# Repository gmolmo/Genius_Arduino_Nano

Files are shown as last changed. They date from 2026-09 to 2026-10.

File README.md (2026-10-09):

<h1 align="center"> 🔵🟢 Genius / Simon - Arduino 🟡🔴 </h1>

<div align="center">

  

</div>

## Descrição do Projeto
O projeto consiste no desenvolvimento do clássico jogo de memória **Genius (ou Simon)** utilizando um **Arduino Nano**. O objetivo do jogo é memorizar e repetir a sequência aleatória de luzes e sons apresentada pelos LEDs e buzzer. É possível selecionar a quantidade de rodadas desejadas e, com o avançar do jogo, o tempo de exibição é diminuído para aumentar a dificuldade.

O desenvolvimento passou pelas etapas de prototipagem em protoboard, soldagem final dos componentes em uma placa perfurada e montagem em um case feito em impressão 3D (feito por membros antigos da **ERUS UFES**).
<div align="center">
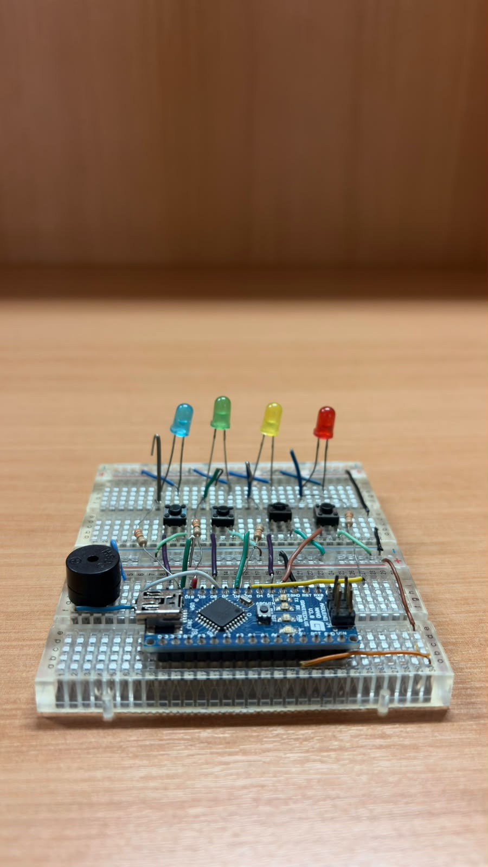
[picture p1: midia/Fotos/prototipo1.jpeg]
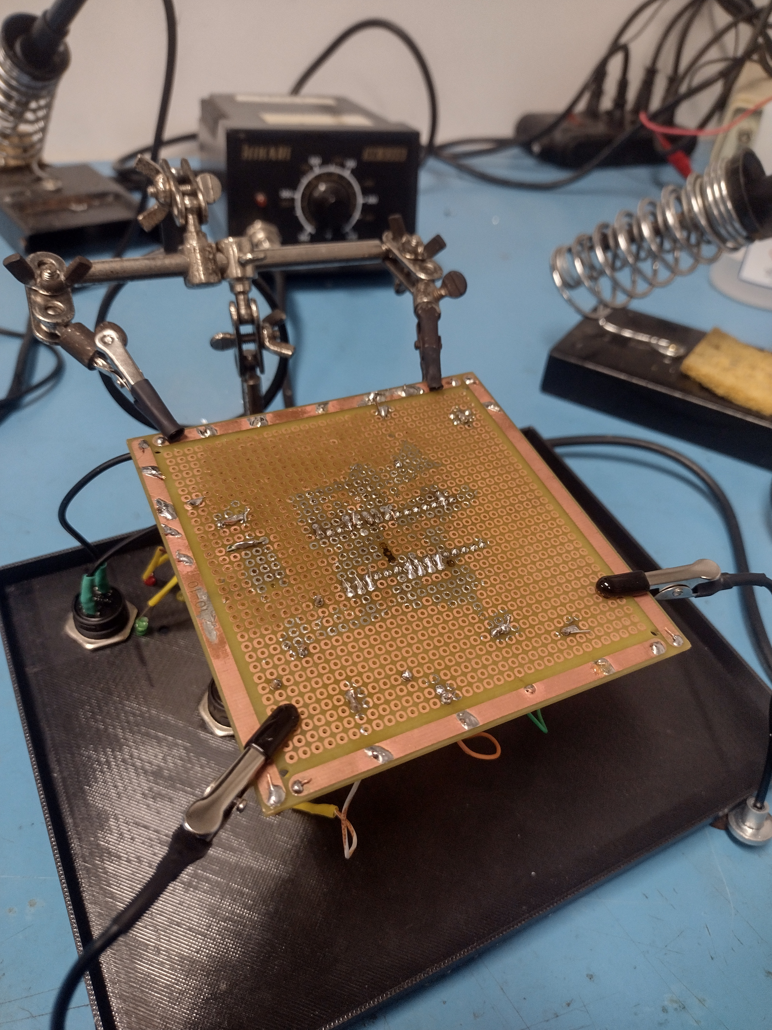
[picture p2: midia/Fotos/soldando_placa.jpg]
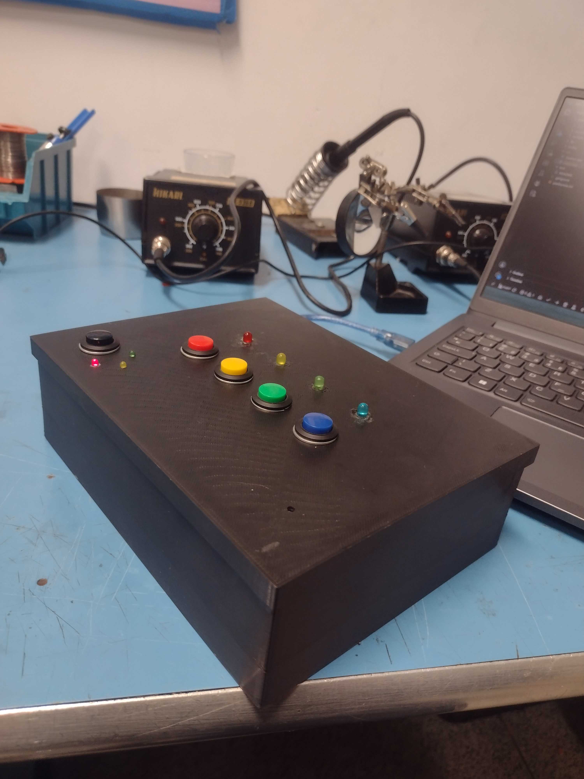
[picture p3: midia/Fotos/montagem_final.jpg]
  
</div>

## ⚙️ Funcionamento

### Software
O código foi inteiramente programado em **C++** modularizado sob o conceito de **TAD (Tipo Abstrato de Dados)**. A estrutura foi dividida em três arquivos principais:
- `Genius.h`: Contém a definição da classe `Genius`, protótipos de métodos e atributos.
- `Genius.cpp`: Implementação da lógica do jogo, controle de som via buzzer, animações de LEDs (Início, Vitória e Game Over), gerenciamento de estados e leitura dos botões.
- `main.cpp`: Executa o setup e o loop principal com a máquina de estados do jogo.

O programa conta com **3 níveis de dificuldade** selecionáveis pelo botão de controle antes do início da partida, indicados por LEDs dedicados.

### Hardware
- **Arduino Nano**: Microcontrolador responsável pelo processamento da lógica.
- **LEDs Coloridos**: 4 LEDs para a sequência do jogo e 3 LEDs para indicação do nível de dificuldade.
- **Push Buttons**: 4 botões para entrada do jogador e 1 botão para seleção de dificuldade.
- **Buzzer Passivo**: Emite tons em frequências específicas para cada LED e reproduz os efeitos sonoros do jogo.
- **Placa Perfurada**: Circuito soldado para garantir durabilidade e conexões firmes.
- **Case 3D**: Case plástico impresso em 3D para abrigar a eletrônica.

## 🪚 Ferramentas

### C++ / Arduino Framework 
Linguagem utilizada no desenvolvimento de toda a lógica do projeto, aplicando orientação a objetos básica e boa organização estrutural.

### PlatformIO (VS Code)  
Ecossistema utilizado para compilação, gerenciamento de dependências e upload do código diretamente para o Arduino Nano através do Visual Studio Code.

## Instruções

Para compilar e enviar o projeto para o Arduino:

1. Certifique-se de ter o **VS Code** instalado com a extensão do **PlatformIO**.
2. Clone o repositório ou baixe o pacote completo de código.
3. Abra a pasta do projeto no VS Code.
4. Conecte o **Arduino Nano** à porta USB do seu computador.
5. Acesse a aba do **PlatformIO** na barra lateral e clique em **Upload** (ou utilize o atalho do VS Code).

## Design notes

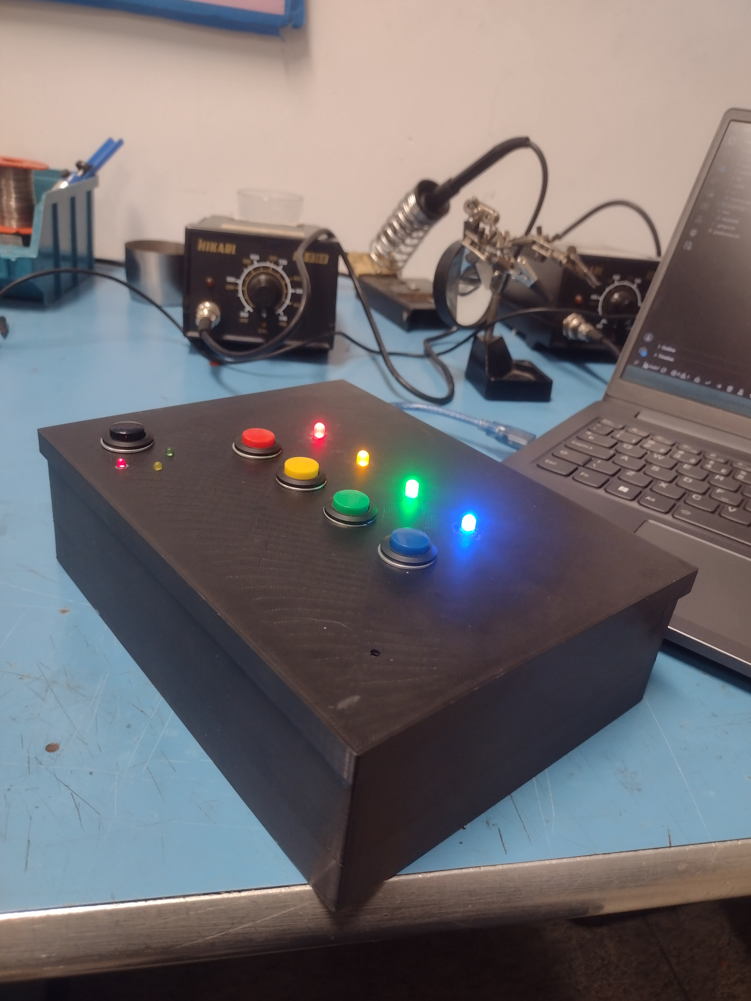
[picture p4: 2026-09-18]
midia/Fotos/funcionando.jpg

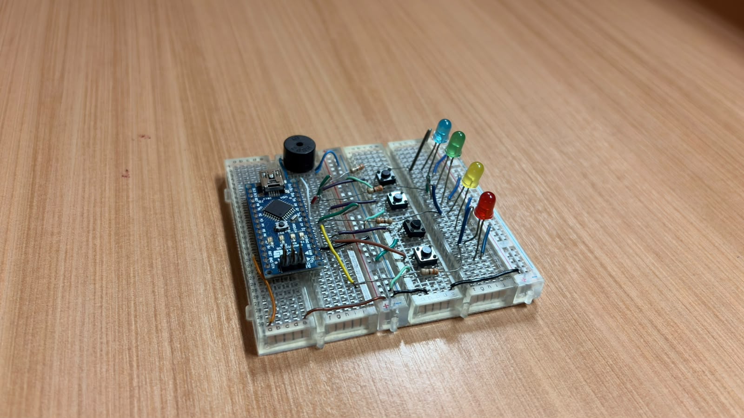
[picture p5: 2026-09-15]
midia/Fotos/prototipo1_.jpeg

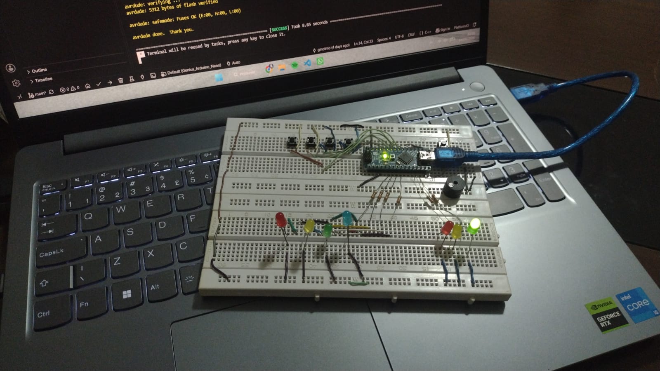
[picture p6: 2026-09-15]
midia/Fotos/prototipo2.jpeg

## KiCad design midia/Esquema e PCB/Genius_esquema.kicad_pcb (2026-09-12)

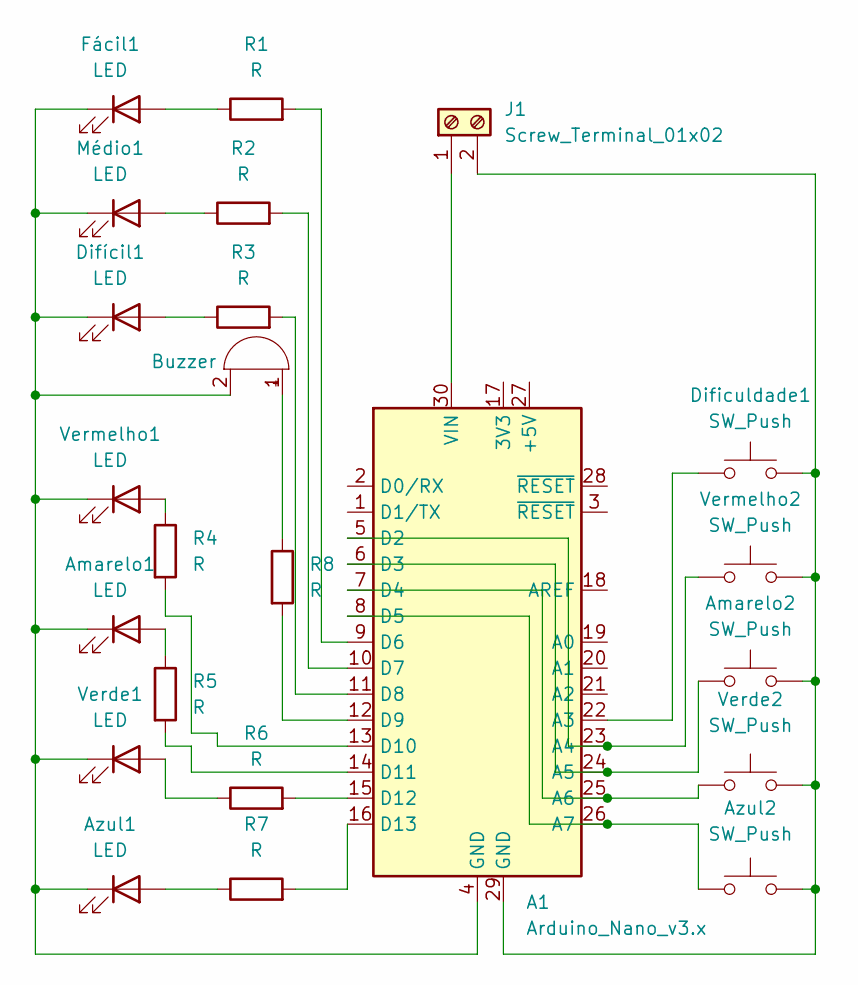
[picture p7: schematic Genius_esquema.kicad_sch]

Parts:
A1: Arduino_Nano_v3.x; Arduino_Nano
Amarelo1: LED; LED_D5.0mm
Amarelo2: SW_Push; PinHeader_1x02_P2.54mm_Vertical
Azul1: LED; LED_D5.0mm
Azul2: SW_Push; PinHeader_1x02_P2.54mm_Vertical
BZ1: Buzzer; Buzzer_12x9.5RM7.6
Dificuldade1: SW_Push; PinHeader_1x02_P2.54mm_Vertical
Difícil1: LED; LED_D5.0mm
Fácil1: LED; LED_D5.0mm
J1: Screw_Terminal_01x02; TerminalBlock_Phoenix_MKDS-1,5-2-5.08_1x02_P5.08mm_Horizont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
Médio1: LED; LED_D5.0mm
R1, R2, R3, R4, R5, R6, R7, R8: R; R_Axial_DIN0207_L6.3mm_D2.5mm_P7.62mm_Horizontal
Verde1: LED; LED_D5.0mm
Verde2: SW_Push; PinHeader_1x02_P2.54mm_Vertical
Vermelho1: LED; LED_D5.0mm
Vermelho2: SW_Push; PinHeader_1x02_P2.54mm_Vertical

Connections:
unnamed: A1.22 (A3), Dificuldade1.1
unnamed: A1.5 (D2), A1.23 (A4), Vermelho2.1
unnamed: A1.6 (D3), A1.24 (A5), Amarelo2.1
unnamed: A1.7 (D4), A1.25 (A6), Verde2.1
unnamed: A1.8 (D5), A1.26 (A7), Azul2.1
unnamed: A1.9 (D6), R1.2
unnamed: A1.10 (D7), R2.2
unnamed: A1.11 (D8), R3.2
unnamed: A1.12 (D9), R8.2
unnamed: A1.13 (D10), R4.2
unnamed: A1.14 (D11), R5.2
unnamed: A1.15 (D12), R6.2
unnamed: A1.16 (D13), R7.2
unnamed: A1.30 (VIN), J1.1
unnamed: Amarelo1.2 (A), R5.1
unnamed: A1.4 (GND), Amarelo1.1 (K), Azul1.1 (K), BZ1.2 (-), Difícil1.1 (K), Fácil1.1 (K), Médio1.1 (K), Verde1.1 (K), Vermelho1.1 (K)
unnamed: Azul1.2 (A), R7.1
unnamed: BZ1.1 (+), R8.1
unnamed: Difícil1.2 (A), R3.1
unnamed: Fácil1.2 (A), R1.1
unnamed: A1.29 (GND), Amarelo2.2, Azul2.2, Dificuldade1.2, J1.2, Verde2.2, Vermelho2.2
unnamed: Médio1.2 (A), R2.1
unnamed: R6.1, Verde1.2 (A)
unnamed: R4.1, Vermelho1.2 (A)

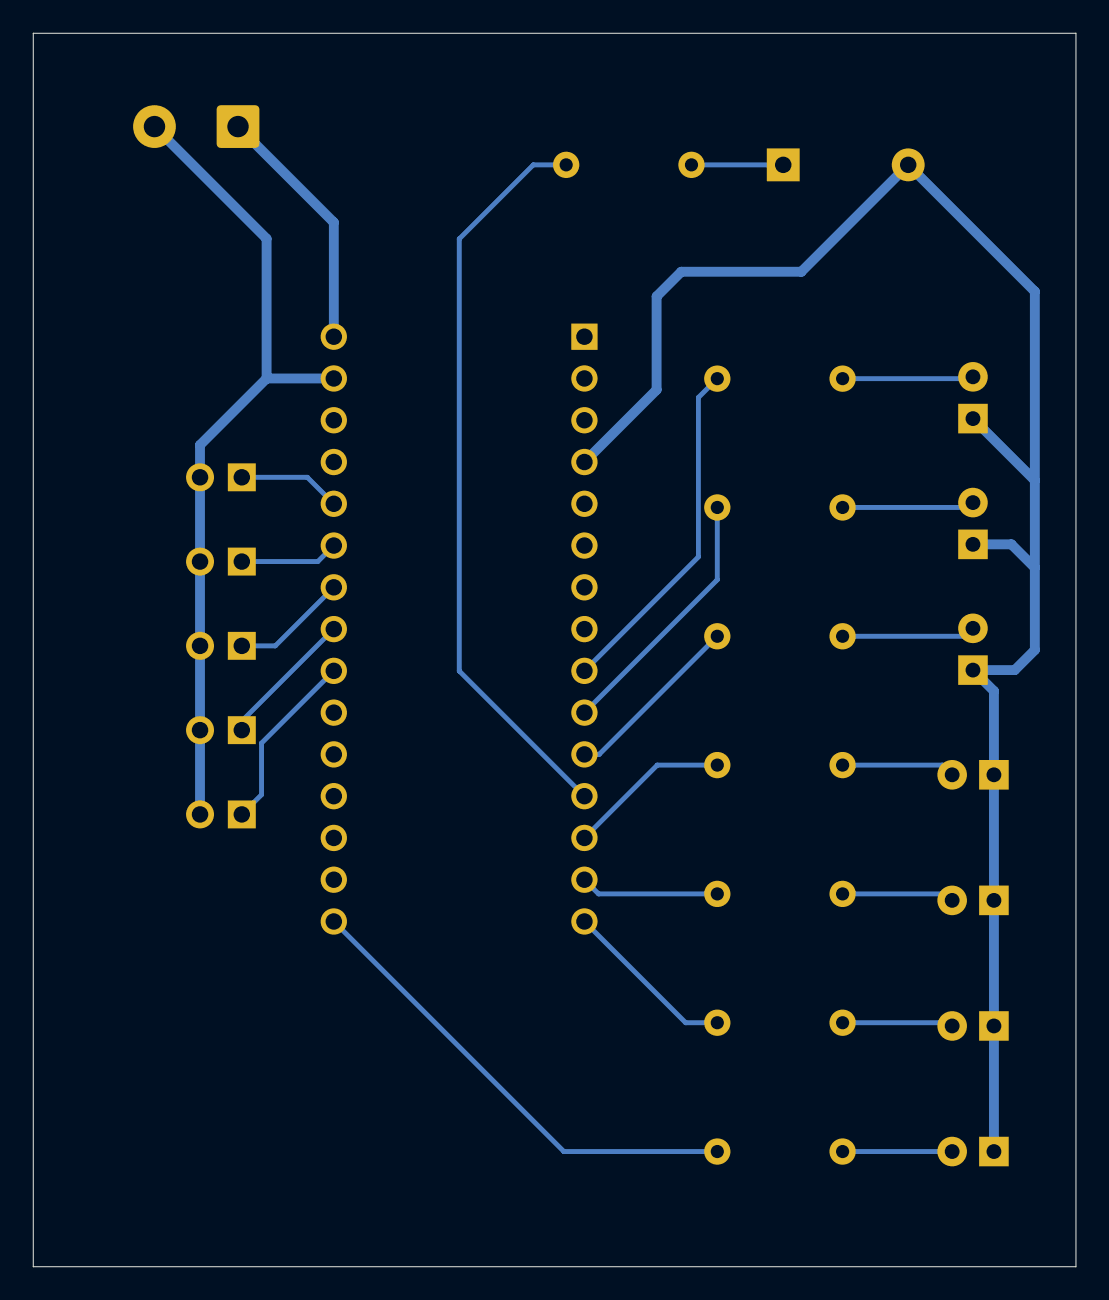
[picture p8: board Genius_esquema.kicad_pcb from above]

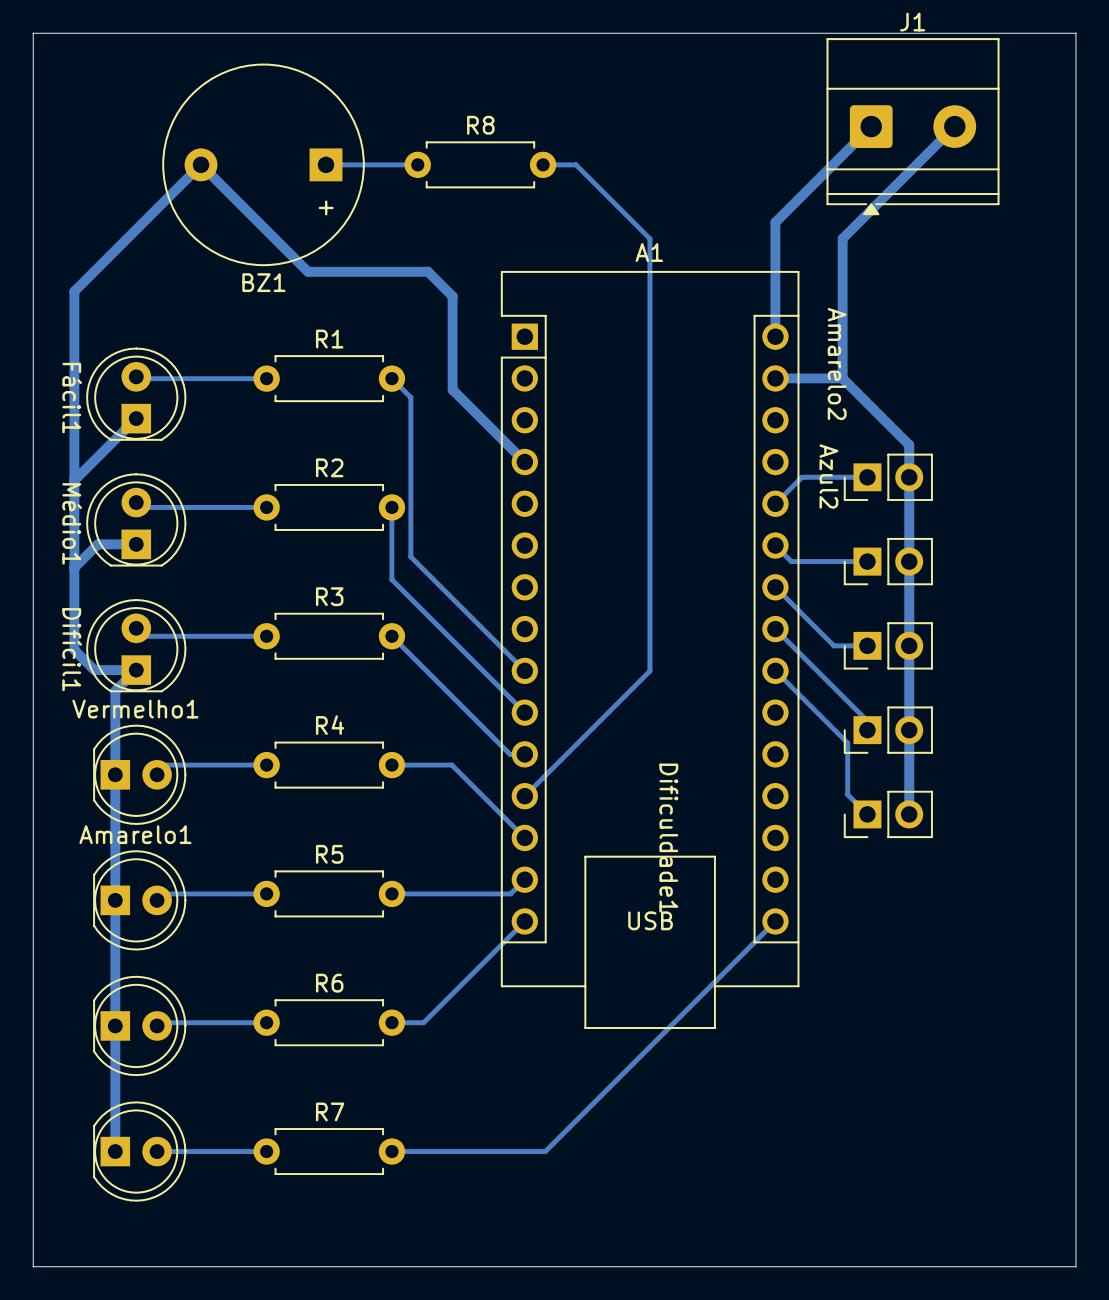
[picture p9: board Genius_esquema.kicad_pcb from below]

Board: 2 copper layers, 63.4 x 75.0 mm, 23 parts (23 on the bottom side), 24 nets.

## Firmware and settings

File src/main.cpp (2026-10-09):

#include <Arduino.h>
#include "Genius.h"

const int pinoLeds[] = {3,4,5,6};
const int pinobotoes[] = {A4,A3,A2,A1,A0};
const int ledsdificuldade[] = {12,11,10};
int buzzer = 13;

int dificuldade = 0;

Genius jogo(pinoLeds,pinobotoes,buzzer,ledsdificuldade);

void setup() {
    jogo.iniciar();
}

void loop() {

  int nRodadas = 5;

  dificuldade = jogo.standby();

  switch (dificuldade)
  {
  case 0:
    nRodadas = 7;
    break;
  case 1:
    nRodadas = 14;
    break;
  case 2:
    nRodadas = 21;
    break;
  default:
    nRodadas = 5;
    break;
  }

  jogo.avisoInicio();
  int resultado = jogo.loopJogo(nRodadas);

  if(resultado == 1)
    jogo.win();
  else
    jogo.gameOver();

  delay(1000);

}

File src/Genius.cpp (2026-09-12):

#include "Genius.h"

Genius::Genius(const int leds[],const int botoes[],int buzzer,const int ledsdificuldade[])
{
    this->pinoLeds = leds;
    this->pinoBotoes = botoes;
    this->pinoBuzzer = buzzer;
    this->ledsdificuldade = ledsdificuldade;
}

void Genius::iniciar()
{
    for(int i = 0; i < 4; i++)
    {
        pinMode(pinoLeds[i],OUTPUT);
        digitalWrite(pinoLeds[i],LOW);
    }
    for(int i = 0; i < 3; i++)
    {
        pinMode(ledsdificuldade[i],OUTPUT);
        digitalWrite(ledsdificuldade[i],LOW);
    }

    for(int i = 0; i < 5; i++)
        pinMode(pinoBotoes[i],INPUT_PULLUP);

    digitalWrite(ledsdificuldade[0],HIGH);
    pinMode(pinoBuzzer,OUTPUT);
    noTone(pinoBuzzer);//certeza de buzzer desligado ao iniciar
}

void Genius::avisoInicio()
{
    int tomContagem = 349;
    int tomInicio = 698;//escalas para o buzzer

    for (int i = 0; i < 3; i++)
    {
        digitalWrite(pinoLeds[i], HIGH);
        tone(pinoBuzzer, tomContagem, 150);//faz uma contagem rápida de 3 sinais sonoros
        delay(150);
        digitalWrite(pinoLeds[i], LOW);
        delay(350);
    }

    for (int i = 0; i < 4; i++) 
    {
        digitalWrite(pinoLeds[i], HIGH);//acende todos os leds
    }
    tone(pinoBuzzer, tomInicio, 400);//faz um ultimo aviso sonoro, mais longo
    delay(400);

    for (int i = 0; i < 4; i++)
    {
        digitalWrite(pinoLeds[i], LOW);//desliga todos os leds
    }
    delay(300);

}

void Genius::ledBuzzer(int led,int duracao,int frequencias[])//duracao pra dificuldades maiores
{
    digitalWrite(pinoLeds[led],HIGH);
    tone(pinoBuzzer,frequencias[led],duracao);
    delay(duracao);//aciona o determinado led e buzzer no intervalo de tempo recebido, na frequencia de cada "led"
    digitalWrite(pinoLeds[led],LOW);
    noTone(pinoBuzzer);
}

void Genius::tocarSequencia(int sorteados[], int nSorteados,int frequencias[])
{
    for(int i = 0; i < nSorteados; i++)
    {
        ledBuzzer(sorteados[i],400,frequencias);
        delay(200);
    }
}

bool Genius::recebeJogada(int rodada, int sequencia[])
{
    int frequencias[] = {262,294,330,349};//cada led tem seu determinado tom

    for(int jogada = 0; jogada <= rodada; jogada++)
    {
        int pressionado = -1;

        while (pressionado == -1 || pressionado == 4)//aguarda o pressionar de um botao
        {
            pressionado = lerBotao();
        }

        ledBuzzer(pressionado,200,frequencias);//aciona o led e o buzzer do botao

        if(pressionado != sequencia[jogada])//caso a jogada tenha sido incorreta, retorna falso
        {
            return false;
        }
    }
    return true;//caso contrario, verdadeiro
}

int Genius::loopJogo(int rodadas)
{
    int frequencias[] = {262,294,330,349};
    int rodadas_jogadas = 0;
    int sequenciaCorreta[rodadas];
    int duracao = 300;

    for(int i = 0; i < rodadas; i++)
        sequenciaCorreta[i] = random(0,4);//preenche o vetor com numeros entre 0 e 3

    delay(500);
    while (true)//loop principal do jogo;  
    {
        for(int i = 0; i <= rodadas_jogadas; i++)
        {

            if((rodadas_jogadas * 10) / rodadas >= 7)//acelera o jogo conforme seu avanço
                duracao = 250;
            if((rodadas_jogadas *10)/ rodadas >= 9)
                duracao = 200;
            ledBuzzer(sequenciaCorreta[i],duracao,frequencias);
            delay(300);
        }
        bool correto = recebeJogada(rodadas_jogadas,sequenciaCorreta);

        if(!correto)
        {
            return 0;
        }

        rodadas_jogadas++;

        if(rodadas_jogadas == rodadas)
            return 1;

        delay(700);
    }
    
}

void Genius::gameOver()
{
    int notasGameOver[] = {220, 196, 175, 146};
    int duracoes[] = {250, 250, 250, 500};

    for (int i = 0; i < 4; i++) {
        for (int j = 0; j < 4; j++) {
            digitalWrite(pinoLeds[j], HIGH);
        }

        tone(pinoBuzzer, notasGameOver[i], duracoes[i]);
        delay(duracoes[i]);

        for (int j = 0; j < 4; j++) {
            digitalWrite(pinoLeds[j], LOW);
        }
        delay(80);
    }
}

int Genius::lerBotao()
{
    for(int i = 0; i < 5; i++)
    {
        if(digitalRead(pinoBotoes[i])==LOW)
        {
            delay(50);
            while(digitalRead(pinoBotoes[i]) == LOW)//espera o jogador soltar o botao completamente 
                delay(50);

            return i;//retorna o botao pressionado
        }
    }
    return -1;
}

int Genius::standby()
{
    int dificuldade = 0;

    LedsDificuldade(dificuldade);

    while (true)//inicia o loop que faz:
    {
        for(int i = 0; i < 4; i++)
            digitalWrite(pinoLeds[i], HIGH);//acende os leds

        for(int m = 0; m < 5000; m++)//verifica se tem botao clicado
        {
            int botao = lerBotao();
            if(botao == 4)
            {
                dificuldade++;
                if(dificuldade > 2)
                    dificuldade = 0;
                LedsDificuldade(dificuldade);
            }

            else if(botao != -1)
            {
                randomSeed(micros() ^ analogRead(A0));
                for(int i = 0; i < 4; i++)
                digitalWrite(pinoLeds[i], LOW);//se tiver, desliga tudo e retorna

                return dificuldade;
            }
        }
        delay(10);
        for(int i = 0; i < 4; i++)
            digitalWrite(pinoLeds[i], LOW);// se nao apaga e verifica de novo 
        delay(10);

        for(int m = 0; m < 5000; m++)
        {
            int botao = lerBotao();
            if(botao == 4)
            {
                dificuldade++;
                if(dificuldade > 2)
                    dificuldade = 0;
                LedsDificuldade(dificuldade);
            }
            else if(botao != -1)
            {
                randomSeed(micros() ^ analogRead(A0));
                for(int i = 0; i < 4; i++)
                digitalWrite(pinoLeds[i], LOW);

                return dificuldade;
            }
        }
    }
}

void Genius::win()
{
int notasVitoria[] = {523, 659, 784, 1046};
    int duracoes[] = {150, 150, 150, 400};

    for (int i = 0; i < 4; i++) {
        for (int j = 0; j < 4; j++) {
            digitalWrite(pinoLeds[j], HIGH);
        }

        tone(pinoBuzzer, notasVitoria[i], duracoes[i]);
        delay(duracoes[i]);

        for (int j = 0; j < 4; j++) {
            digitalWrite(pinoLeds[j], LOW);
        }

        delay(60);
    }
}
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

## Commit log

2026-09-09 criação do repo para teste do protoripo 1
2026-09-09 Definicao do .h de teste inicial
2026-09-09 implementada a funcao de leitura dos botoes
2026-09-09 Implementada função StandBy, que aguarda o inicio do jogo
2026-09-10 Funcao de aviso do inicio adicionada
2026-09-10 primeira versao do loop de jogo
2026-09-10 corrigido erro na funcao ledBuzzer
    [Genius.cpp, main.cpp]
2026-09-11 main adaptada para receber uma dificuldade selecionada pelo usuario
2026-09-11 main adaptada para receber uma dificuldade selecionada pelo usuario, com modificacoes de assinaturas
2026-09-11 finalizada versao 2 do prototipo, com seleção de dificuldade pelo usuario
2026-09-11 correcao de calculos e melhor aleatorizacao das sequencias
2026-09-12 versao 1 da PCB para o Genius
    [Genius_esquema.kicad_pcb, Genius_esquema.kicad_sch]
2026-09-15 corrigido erro de reset da dificuldade
    [Genius_esquema.kicad_pcb, Genius_esquema.kicad_sch]
2026-09-15 limpeza de backups desnecessários
